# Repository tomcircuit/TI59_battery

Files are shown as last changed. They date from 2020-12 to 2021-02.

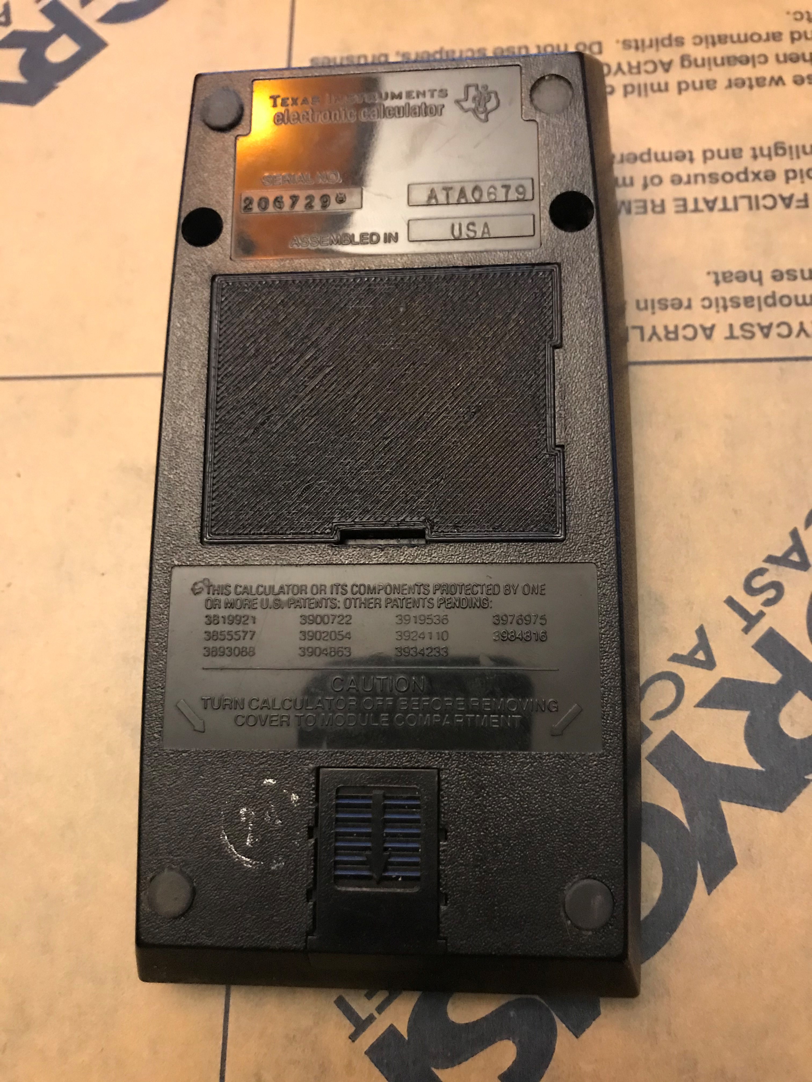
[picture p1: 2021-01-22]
media/TI-59_rear_view_installed.jpg

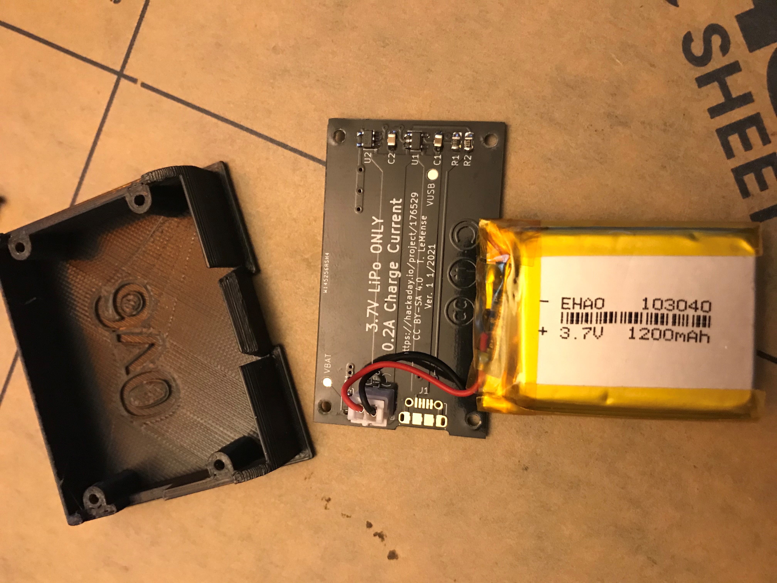
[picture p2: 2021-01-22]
media/TI-59_pack_disassembled.jpg

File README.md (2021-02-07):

 # TI59_battery - LiPo Battery for TI-58/59 Calculators
 
This is my attempt at a LiPo-based battery pack for Texas Instruments Calculators that use the BP01 battery pack,  specifically the TI-58, TI-58C, and TI-59. The original NiCd packs are all dead by now, and rebuilding them is difficult, mostly because it requires cutting apart and then carefully re-assembling the plastic battery retention frame. I thought it would be fun to design a 3D printed housing and re-use the circuitry from my rechargeable HP LiPo battery pack. 

> LiPo chemistry has very specific care-and-feeding when it comes to recharging, **the original charger and charging circuitry will not suffice.**  For this reason, I include a USB receptacle, which allows for charging when removed from the calculator.

The basic idea is to use a gold-flashed (ENIG) PCB as the contact substrate, and mount the LiPo, USB micro B receptacle, and charging circuitry on the opposite side. A **charging LED** is placed on the same side as the contact pads, but in areas where there will be no mechanical interference. A 3D printed plastic holder ties it all together, and mates with the TI calculator case. 
 
## The Housing
I  have several original TI BP01 battery packs, so I was able to carefully measure them and create a 3D model using OpenSCAD. This is essentially a 3D solid 'programming language' which (for me) is much easier to work with than an interactive 3D CAD program. It took several iterations to arrive at a working holder design that would 3D print (FDM) reliably. Note that the holder is best printed "flat side down", but that this orientation is **not ideal** for the retention tab; it wants to break along the FDM layers. I have had good luck with PLA+ material, and even better results with PTEG. 

## The PCB 
The PCB holds the USB micro B connector, the charging circuitry, the protection circuitry, a connector for the LiPo battery, and most importantly the pads that mate with the contacts in the calculator.  The overall size of the PCB is 53mm x 28mm. The material is 1.6mm thick FR4. So that the contact pads do not  tarnish over time, I chose a gold-flash treatment (ENIG). 

The schematic and PCB were designed using KiCAD.

## The LiPo Battery
I wanted a 1S (3.7V) LiPo battery in the neighborhood of 1200mAhr that would fit within the confines of the original pack envelope. This led me to a size "103040" LiPo battery. 

## Putting It All Together
Pretty self-explanatory. I used 0805 size components to allow for easy hand-soldering. Note that D1 (LED) and Z1 (Zener) are both polarized, so pay attention to that. Soldering the USB connector requires a fine-tip iron and some patience, or a hot-air solder station. I use the latter with very good results. 

Connect the battery to the PCB, double-checking that the polarity of the LiPo is matching the **+** and **-** marks on the PCB. Place the battery into the holder in between the two pairs of screw bosses, and then press the PCB into place above it. Four #2 self-tapping stainless steel screws secure the PCB into the 3D printed holder.

## Charge It
Connect a micro-B cable to the board and charge the LiPo battery. The LED will stay lit during the charging process, and extinguish when it is completed. The charge current is about 220mA (0.2C for a 1200mAhr battery). You can adjust R1 to change the current (decrease R1 will increase charging current) if you need to. It took about three hours to charge my battery.

## Use It!
Install the pack into the calculator. Be very careful with the delicate latch retention tab when inserting and removing the holder, because it is fragile and prone to breakage. If it does break, you can usually re-attach the tab with Krazy Glue. Enjoy using your vintage TI programmable calculator!

>February 7. 2021
>Tom LeMense
> Written with [StackEdit](https://stackedit.io/). #

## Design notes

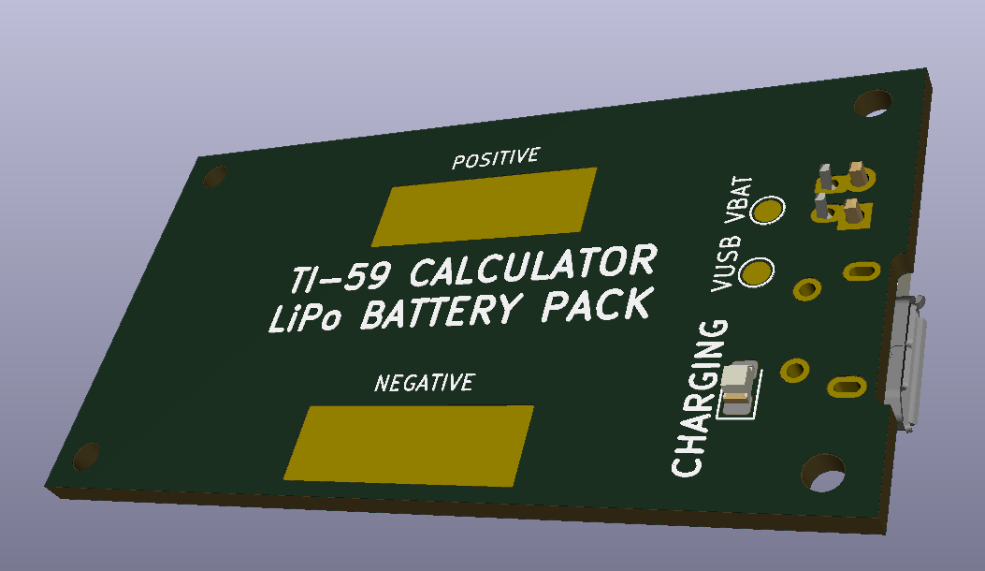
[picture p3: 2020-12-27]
media/initial_pcb_render.PNG

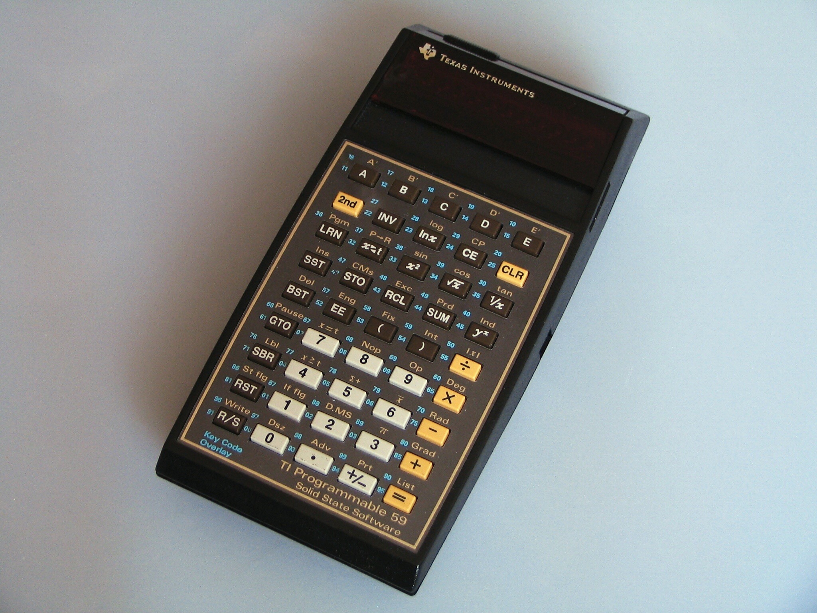
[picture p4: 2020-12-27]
media/TI-59_Half-side_view.jpg

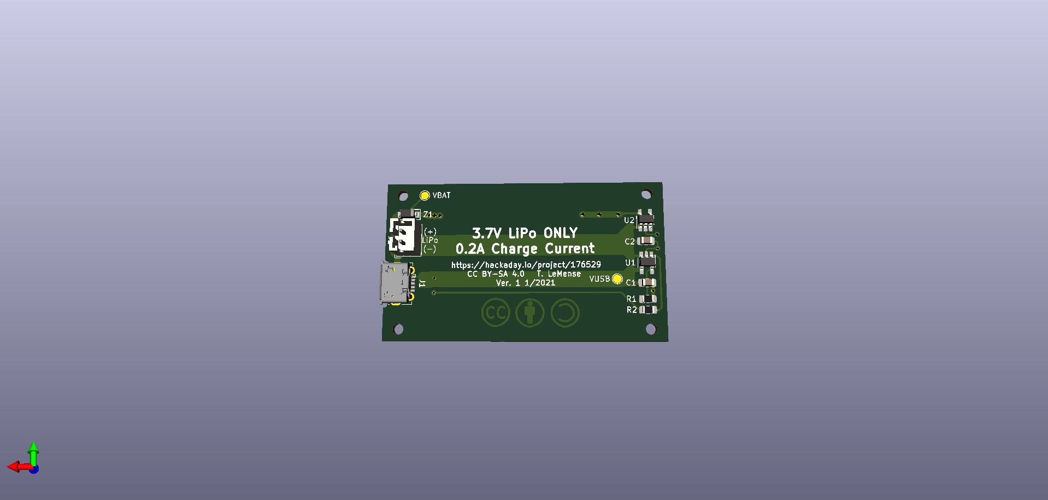
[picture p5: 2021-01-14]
media/routed_pcb_render_bottom.png

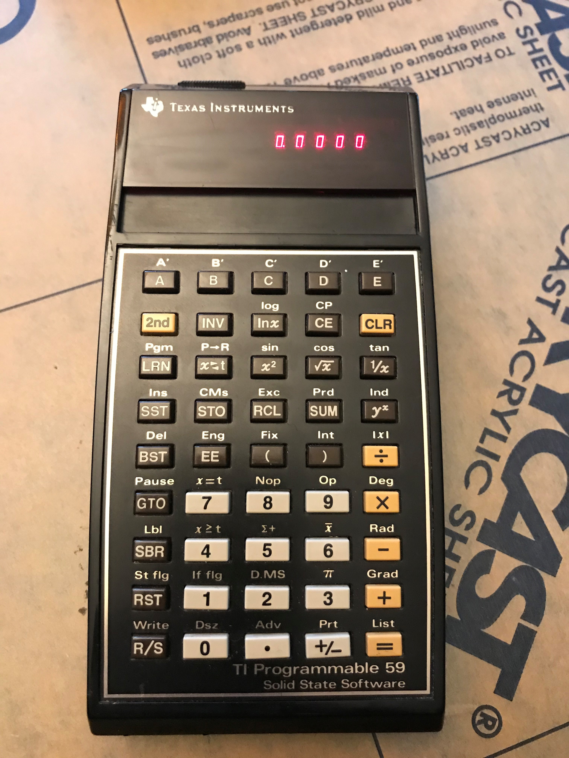
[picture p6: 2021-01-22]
media/TI-59_running.jpg

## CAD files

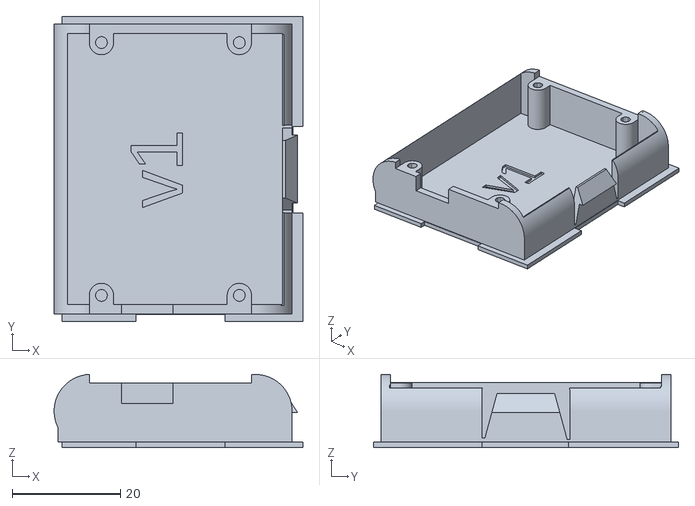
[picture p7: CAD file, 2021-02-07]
mechanical/TI-59_LiPo_holder_1v0.stl
46.0 x 56.4 x 13.5

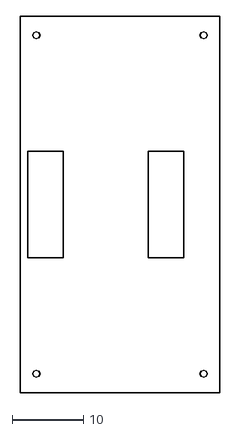
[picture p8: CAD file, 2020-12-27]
mechanical/TI-59_LiPo_holder_cut4_.dxf
28.0 x 53.0

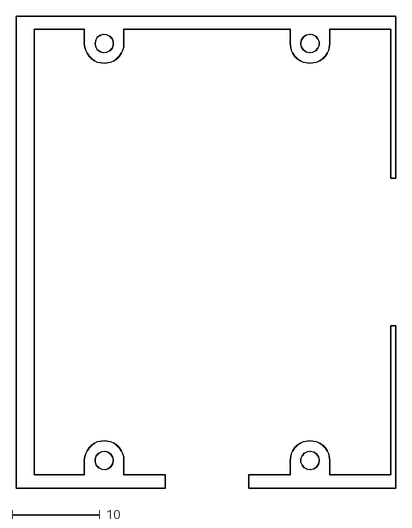
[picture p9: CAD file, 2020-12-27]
mechanical/TI-59_LiPo_holder_cut3_.dxf
43.4 x 53.9

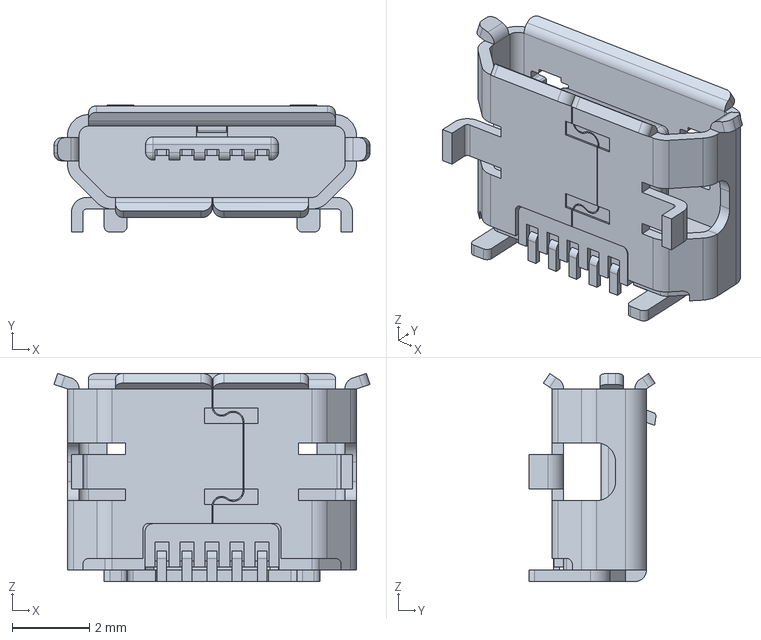
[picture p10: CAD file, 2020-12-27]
electrical/105017-0001_stp/1050170001.stp
8.20 x 3.30 x 5.40 mm

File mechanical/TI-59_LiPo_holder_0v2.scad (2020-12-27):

/*
  TI-58/59 Battery Lid
  This is intended to hold a PCB and a LiPo battery,
  and charge from USB. 

  Dimensions more or less 'cribbed' from a BP-1 and an
  existing STL model that I imported into FreeCAD to measure.

  Version 1.1
  T. LeMense
  December 21, 2020
*/


$fa = 1;
$fs = 0.4;

// baseplate (first surface)
base_t = 1.0;
base_w = 44.85;
base_l = 56.4;
ledge_t = 1.25;
ledge_t1 = 0.75;
ledge_t2 = 1.85;

// PCB information
pcb_t = 1.6;
pcb_w = 28;
pcb_l = 53;
pcb_z = 13.5-pcb_t;
pcb_x = 6.5;

// USB connector cutout
// MOLEX 1050170001
usb_t = 3.75;
usb_w = 9.5;

// "superstructure"
super_w = base_w - ledge_t2 + ledge_t1;
super_l = base_l - 2*ledge_t;
super_h = 5.7;  // the "straight rise" from baseplate
super_z = base_t;  // the "altitude" at which everything starts
super_wall_t = 1.5;
super_floor_t = 0.5;
round_rad = (pcb_z+pcb_t+super_z)/2;

// latch 'tab' is extruded 2D
latch_tab_t = super_wall_t + 0.75;
latch_tab_h = 2.8;
latch_tab_t2 = 0.25;
latch_tab_w = 16.9;
latch_tab_z = 4.95;

p0 = [0, 0];
p1 = [0, latch_tab_h];
p2 = [latch_tab_t2,latch_tab_h];
p3 = [latch_tab_t,0];
tab_points = [p0, p1, p2, p3];
    
// hinge cutouts is extruded 2D
latch_tab_w2 = 12.0;
latch_tab_h2 = super_h+latch_tab_h;

p4 = [0, 0];
p5 = [0, latch_tab_h2];
p6 = [(latch_tab_w - latch_tab_w2)/2,latch_tab_h2];
p7 = [latch_tab_t2,0];
cutout_points = [p4, p5, p6, p7];

echo("inside cavity width is", super_w-2*super_wall_t);
echo("inside cavity length is", super_l-2*super_wall_t);
echo("PCB dimensions are ",pcb_w," x ",pcb_l);

module RoundedBoss(side,height,hole_dia){
    difference() {
        union() {
        cube([side,side/2,height]);
        translate([side/2,side/2,0])
        cylinder(r=side/2,h=height);
        }
        
        translate([side/2,side/2,height/3])
        cylinder(r=hole_dia/2,h=height/1.5);
    }
}

function RoundedBossHoleCenter(side,height,hole_dia) = [side/2,side/2,0];
   

/* 
  Define some "cuts" to export as DXF, to help
  guide the PCB size (cut 1) and PCB hole placement
  (cut 2).

  uncomment the projection.. and the desired translate line
*/

//projection(cut = true) 
//translate([0,0,-base_t/2])   //cut1
//translate([0,0,-pcb_z])   //cut2
//translate([0,0,-10.5])  //cut3
//translate([0,0,-20]) //cut4

union(){
difference() {
    union() {
        
// additive items        
        
    // the baseplate
    cube(size=[base_w, base_l, base_t]);
        
    // the superstructure inner volume
    translate([-0.75, 1.25, super_z])
    cube([super_w, super_l,super_h]); 

    // the locking tab
    translate([-ledge_t1-super_wall_t+super_w,ledge_t+(super_l/2)+(latch_tab_w/2),latch_tab_z+super_z]) 
    rotate([90,0,0]) 
    linear_extrude(height=latch_tab_w) polygon(tab_points);
        
    // the rounded rear wall
    translate([-ledge_t1+5.5,ledge_t,round_rad]) 
    rotate([-90,0,0]) 
    cylinder(r=round_rad,h=super_l);
        
    // the two rounded walls on either side of latch
    translate([-ledge_t1+super_w-round_rad,ledge_t,round_rad]) 
    rotate([-90,0,0]) 
    cylinder(r=round_rad,h=super_l/2-latch_tab_w/2);

    translate([-0.75+super_w-round_rad,base_l-ledge_t,round_rad]) 
    rotate([90,0,0]) 
    cylinder(r=round_rad,h=super_l/2-latch_tab_w/2);
        
    // complete the side walls
    translate ([(5-0.75),ledge_t,super_z])
    cube([super_w-12,super_wall_t,2*round_rad-super_z]);        

    translate ([(5-0.75),base_l-ledge_t-super_wall_t,super_z])
    cube([super_w-12,super_wall_t,2*round_rad-super_z]);
    }
    
// subtractive items            
    
    // remove the locking tab release slot
    translate([base_w - 1.85,1.25+(super_l/2)-(latch_tab_w*0.9/2),-0.25]) 
    cube([2,latch_tab_w*0.9,2]);
    
    // remove the polarizing baseplate notch
    translate([13.8,-1.25,-0.5]) cube([16.4,2.5,2]);
        
    // remove the two hinge cutouts
    translate([-1-super_wall_t+super_w,1.25+(super_l/2)-(latch_tab_w/2)-0.1,super_z])
    rotate([90,0,90])
    linear_extrude(height=2*super_wall_t)
    polygon(cutout_points);
    
    translate([-1+super_wall_t+super_w,1.25+(super_l/2)+(latch_tab_w/2)+0.1,super_z])
    rotate([90,0,-90]) 
    linear_extrude(height=2*super_wall_t) 
    polygon(cutout_points);

    // flatten the rounded wall edges
    translate([-2, 1.25+super_wall_t, super_z+11.5])
    cube([5,super_l-2*super_wall_t,5]);
    translate([base_w-4, 1.25+super_wall_t, super_z+10])
    cube([5,super_l-2*super_wall_t,5]);

    // remove cutout for PCB
    translate([pcb_x,0,super_z+pcb_z])
    cube([pcb_w, pcb_l+4, pcb_t+1]);
    
    // remove cutout for USB micro B
    translate([pcb_x+6,0,super_z+pcb_z-usb_t])
    cube([usb_w,5,5]);

    // remove the superstructure insides
    translate([-0.75+super_wall_t, 1.25+super_wall_t, super_z+super_floor_t])
    cube([super_w-2*super_wall_t, super_l-2*super_wall_t, 20]); 
 
}


// mounting screw bosses
boss_l = 4.5;
boss_dia = 2.1;
boss_inset = (boss_l - boss_dia)/4;

translate([pcb_x,ledge_t+super_wall_t-boss_inset,super_z])
RoundedBoss(boss_l,pcb_z,boss_dia);  // for #2 screw
h1 = [pcb_x+boss_l/2,ledge_t+super_wall_t-boss_inset+boss_l/2,0];

translate([pcb_x+pcb_w-boss_l,ledge_t+super_wall_t-boss_inset,super_z])
RoundedBoss(boss_l,pcb_z,boss_dia);  // for #2 screw
h2 = [pcb_x+pcb_w-boss_l/2,ledge_t+super_wall_t-boss_inset+boss_l/2,0];

translate([pcb_x+boss_l,base_l-ledge_t-super_wall_t+boss_inset,super_z])
rotate([0,0,180])
RoundedBoss(boss_l,pcb_z,boss_dia);  // for #2 screw
h3 = [pcb_x+boss_l/2,base_l-ledge_t-super_wall_t+boss_inset-boss_l/2,0];

translate([pcb_x+pcb_w,base_l-ledge_t-super_wall_t+boss_inset,super_z])
rotate([0,0,180])
RoundedBoss(boss_l,pcb_z,boss_dia);  // for #2 screw
h4 = [pcb_x+pcb_w-boss_l/2,base_l-ledge_t-super_wall_t+boss_inset-boss_l/2,0];


// uncomment this block if a pcb "model" is desired
pcb_model_z = 20;
pcb_model_z = pcb_z+pcb_t/2;
//hole_dia = 0.086 * 25.4;
pad_width = 5;
pad_length = 15;
hole_dia = 1;
pad1_x = 10;
pad2_x = 27;
echo ("pad1 center ",[pad1_x,base_l/2]);
echo ("pad2 center ",[pad2_x,base_l/2]);

translate([0,0,pcb_model_z]) 
    color("green") 
    linear_extrude(height=pcb_t) 
    difference(){
       translate ([pcb_x,(base_l-pcb_l)/2,0]) square ([pcb_w,pcb_l],false); 
       translate([pad1_x,base_l/2,pcb_model_z])        square([pad_width,pad_length],true);
       translate([pad2_x,base_l/2,pcb_model_z])        square([pad_width,pad_length],true);
       translate(h1) circle(d = hole_dia);
       translate(h2) circle(d = hole_dia);
       translate(h3) circle(d = hole_dia);
       translate(h4) circle(d = hole_dia);
    }
//*/
}

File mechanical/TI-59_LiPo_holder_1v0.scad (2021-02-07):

/*
  TI-58/59 Battery Lid for LiPo Pack V1
  This is intended to hold a PCB and a LiPo battery,
  and charge from USB. 

  Dimensions measured from several TI-58 and TI-59 calculators and two BP-1A packs.
  
  0.4 and earlier - very rough 
  
  0.5 - extended tab overhang to increase engagement with calculator latch
  
  0.6 - reduced contact_zabs to 13.5 to prevent PCB screws and LED from interfering with inside of TI-59
  
  0.7 - rounded cutout on inside of tab hinge to help de-stress and prevent breakage. Increased slope of latch tab to make insertion into calculator easier
  
  0.8 - removed cutout (made tab worse). This becomes V1

  T. LeMense
  February 7, 2021
*/


$fa = 1;
$fs = 0.4;

// L is length, and is along Y AXIS
// W is width, and is along X AXIS
// H is height, and is along Z AXIS

// baseplate (first surface)
base_t = 1.0;  // base thickness (measured)
base_w = 44.5;  // width (measured)
base_w3 = 14.4;  // ledge width from pol slot to latch end (measured)
base_w1 = 13.6;  // ledge w from round end to pol slot (measured)
base_w2 = base_w-base_w1-base_w3;  // calculate pol slot w (measured 16.4mm)
base_l = 56.4;   // length (measured)
ledge_t = 1.4;  // ledge along short sides (improved)
ledge_t1 = 0.75; // ledge step-back along curved long side
ledge_t2 = 2.0;  // ledge along latch side (measured)

//contact Z offset (absolute to bottom of base)
//keep below 15 to avoid interference with innards of TI59!
contact_zabs = 13.5; 

// PCB information
pcb_t = 1.6;
pcb_w = 30;
pcb_l = 53;
pcb_z = contact_zabs-pcb_t-base_t;
pcb_x = 5;

// USB connector cutout
// MOLEX 1050170001
usb_h = 3.75;
usb_w = 9.5;

// "superstructure"
super_w = base_w - ledge_t2 + ledge_t1; // width (short edge)
super_l = base_l - 2*ledge_t;  // length (long edge)
super_h = 5.7;  // the "straight rise" from baseplate
super_wall_t = 1.75;
super_floor_t = 0.5; // additional floor thickness
round_rad = (pcb_z+pcb_t+base_t)/2;

// latch 'tab' is an extruded polygon
latch_tab_w = super_wall_t + 1.0; // extent of tab past wall
latch_tab_h = 3.5;
latch_tab_w2 = 0.5;
latch_tab_l = 16.0;
latch_tab_z = 5.5;   // relative to base_t

p0 = [0, 0];
p1 = [0, latch_tab_h];
p2 = [latch_tab_w2,latch_tab_h];
p3 = [latch_tab_w,0];
tab_points = [p0, p1, p2, p3];
    
// hinge cutout is extruded 2D
latch_tab_l2 = 10.0;
latch_tab_h2 = super_h+latch_tab_h;

p4 = [0, 0];
p5 = [0, latch_tab_h2];
p6 = [(latch_tab_l - latch_tab_l2)/2,latch_tab_h2];
p7 = [latch_tab_w2,0];
cutout_points = [p4, p5, p6, p7];

echo("inside cavity width is", super_w-2*super_wall_t);
echo("inside cavity length is", super_l-2*super_wall_t);
echo("PCB dimensions are ",pcb_w," x ",pcb_l);

module RoundedBoss(side,height,hole_dia){
    difference() {
        union() {
        cube([side,side/2,height]);
        translate([side/2,side/2,0])
        cylinder(d=side,h=height);
        }
        
        translate([side/2,side/2,height/3])
        cylinder(d=hole_dia,h=height/1.5);
    }
}

function RoundedBossHoleCenter(side,height,hole_dia) = [side/2,side/2,0];
   

/* 
  Define some "cuts" to export as DXF, to help
  guide the PCB size (cut 1) and PCB hole placement
  (cut 2). These are translated to place PCB corner at 
  origin.  Note that the PCB model must be enabled, and
  the PCB Z at 20, in order to make cut4 useful.

  uncomment the projection.. and the desired translate line. Render. Export as DXF
*/

//projection(cut = true) 
//translate([-pcb_x,-(base_l-pcb_l)/2,-base_t/2])   //cut1 = base extent
//translate([-pcb_x,-(base_l-pcb_l)/2,-10.5])  //cut3 = cavity inside w.r.t PCB
//translate([-pcb_x,-(base_l-pcb_l)/2,-20]) //cut4 = PCB cuts + contacts + holes

union(){
difference() {
    union() {
        
// additive items        
        
    // the baseplate
    cube(size=[base_w, base_l, base_t]);
        
    // the superstructure inner volume
    translate([-ledge_t1, ledge_t, base_t])
    cube([super_w, super_l,super_h]); 

    // the locking tab
    translate([-ledge_t1-super_wall_t+super_w,ledge_t+(super_l/2)+(latch_tab_l/2),latch_tab_z+base_t]) 
    rotate([90,0,0]) 
    linear_extrude(height=latch_tab_l) polygon(tab_points);
        
    // the rounded rear wall
    translate([-ledge_t1+6,ledge_t,round_rad]) 
    rotate([-90,0,0]) 
    cylinder(r=round_rad,h=super_l);
        
    // the two walls to either side of latch
    translate([-ledge_t1+super_w-round_rad,ledge_t,round_rad]) 
    rotate([-90,0,0]) 
    cylinder(r=round_rad,h=super_l/2-latch_tab_l/2);

    translate([-ledge_t1+super_w-round_rad,base_l-ledge_t,round_rad]) 
    rotate([90,0,0]) 
    cylinder(r=round_rad,h=super_l/2-latch_tab_l/2);
        
    // complete the side walls
    translate ([(5-0.75),ledge_t,base_t])
    cube([super_w-12,super_l,2*round_rad-base_t]); 
    
    }
    
// subtractive items            
    
    // remove tab release slot from base
    translate([base_w - 1.85,1.25+(super_l/2)-(latch_tab_l/2),-0.25]) 
    cube([2,latch_tab_l,2]);
    
    // remove polarizing notch from base
    translate([base_w1,-1.25,-0.5]) cube([base_w2,2.50,2]);
        
    // remove the two hinge cutouts
    translate([super_w-super_wall_t-1,ledge_t+(super_l/2)-(latch_tab_l/2)-0.1,base_t+0.75])
    rotate([90,0,90])
    linear_extrude(height=2*super_wall_t)
    polygon(cutout_points);
    
    translate([-1+super_wall_t+super_w,ledge_t+(super_l/2)+(latch_tab_l/2)+0.1,base_t+0.5])
    rotate([90,0,-90]) 
    linear_extrude(height=2*super_wall_t) 
    polygon(cutout_points);
    
    // de-stress the tab hinge
//translate([-ledge_t1+super_w-2.5,ledge_t+(super_l/2)-(latch_tab_l/2)-0.1,base_t+2.25])
//rotate([-90,0,0])
//cylinder(r=1.75,h=latch_tab_l);

    // flatten the rounded wall edges
    translate([-2, 1.25+super_wall_t, base_t+12.5])
    cube([5,super_l-2*super_wall_t,5]);
    translate([base_w-4, 1.25+super_wall_t, base_t+10])
    cube([5,super_l-2*super_wall_t,5]);

    // remove cutout for PCB
    translate([pcb_x,0,base_t+pcb_z])
    cube([pcb_w, pcb_l+4, pcb_t+1]);
    
    // remove cutout for USB micro B
    translate([pcb_x+6,0,base_t+pcb_z-usb_h])
    cube([usb_w,4*super_wall_t,2*usb_h]);

    // remove the superstructure insides
    translate([super_wall_t-ledge_t1, ledge_t+super_wall_t, base_t+super_floor_t])
    cube([super_w-2*super_wall_t, super_l-2*super_wall_t, 20]); 
    
    // etch some text into the floor
    translate([base_w/2,base_l/2,base_t])
    rotate([0,0,90])
    linear_extrude(3)
    text( "v1", size= 10, ,halign = "center", valign = "bottom" );
}

// mounting screw bosses
boss_l = 4.5;
boss_h_dia = 2.2;
boss_inset = (boss_l - boss_h_dia)/4;

translate([pcb_x,ledge_t+super_wall_t-boss_inset,base_t])
RoundedBoss(boss_l,pcb_z,boss_h_dia);  // for #2 screw
h1 = [pcb_x+boss_l/2,ledge_t+super_wall_t-boss_inset+boss_l/2,0];

translate([pcb_x+pcb_w-boss_l,ledge_t+super_wall_t-boss_inset,base_t])
RoundedBoss(boss_l,pcb_z,boss_h_dia);  // for #2 screw
h2 = [pcb_x+pcb_w-boss_l/2,ledge_t+super_wall_t-boss_inset+boss_l/2,0];

translate([pcb_x+boss_l,base_l-ledge_t-super_wall_t+boss_inset,base_t])
rotate([0,0,180])
RoundedBoss(boss_l,pcb_z,boss_h_dia);  // for #2 screw
h3 = [pcb_x+boss_l/2,base_l-ledge_t-super_wall_t+boss_inset-boss_l/2,0];

translate([pcb_x+pcb_w,base_l-ledge_t-super_wall_t+boss_inset,base_t])
rotate([0,0,180])
RoundedBoss(boss_l,pcb_z,boss_h_dia);  // for #2 screw
h4 = [pcb_x+pcb_w-boss_l/2,base_l-ledge_t-super_wall_t+boss_inset-boss_l/2,0];



/*
// uncomment this block if a pcb "model" is desired
pcb_model_z = 20;
//pcb_model_z = pcb_z+base_t;
//hole_dia = 0.086 * 25.4;
pad_width = 5;
pad_length = 15;
hole_dia = 1;
pad1_x = 10;
pad2_x = 27;
echo ("pad1 center ",[pad1_x,base_l/2]);
echo ("pad2 center ",[pad2_x,base_l/2]);

translate([0,0,pcb_model_z]) 
    color("green") 
    linear_extrude(height=pcb_t) 
    difference(){
       translate ([pcb_x,(base_l-pcb_l)/2,0]) square ([pcb_w,pcb_l],false); 
       translate([pad1_x,base_l/2,pcb_model_z])        square([pad_width,pad_length],true);
       translate([pad2_x,base_l/2,pcb_model_z])        square([pad_width,pad_length],true);
       translate(h1) circle(d = hole_dia);
       translate(h2) circle(d = hole_dia);
       translate(h3) circle(d = hole_dia);
       translate(h4) circle(d = hole_dia);
    }
//*/
}

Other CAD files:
mechanical/TI-59_LiPo_holder_0v5.scad
mechanical/TI-59_LiPo_holder_0v5_latch_test.scad

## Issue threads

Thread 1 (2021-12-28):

Suggestion - simple way to let TI charging circuit power and charge calculator

magore, 2021-12-28:
I love your project. This is just a suggestion and not a bug report.

I have a number of TI-59 calculators and your project got me thinking.
I wondered if there was a way to use the existing TI charging circuit (basically a bridge rectifier feed from an externally AC transformer - that was current limited by design) to both charge and power the calculator when plugged in?

First requirement is filter and stabilize the power from the spring contacts. Let that filtered voltage feed a Lipo charging circuit in the battery pack that provides both load/out and charging on its output. When the charger is plugged in the calculator runs from the charger and the LIPO can also charge if needed. When not plugged in calculator runs only from the LIPO. The bridge rectifier prevents back flow from the charger.

Testing I have tried - I have connected a simple LIPO charging circuit to the spring contacts filtered with just a 1000uF cap. With the calculator OFF the spring contacts measure 4.3V and can fully charge the LIPO. However with the calculator ON the voltage drops to 4.0V. So basically the LIPO will not get a full charge unless the calculator is off.

tomcircuit, 2021-12-31:
Thanks for writing, and I’m glad you found my project interesting! I has some thoughts about trying to do what you propose, but didn’t like the complexity (i.e. I was lazy!)

I seem to recall reading that the TI AC charger current limiting was set so that it would just manage to trickle charge the NiCd cells while the calc was operating. So your measurement of 4V with calc on (and no card reader motor I presume) sounds about right.  I think the most straightforward solution would be to use a boost-type charging circuit, such as used with solar cells. You would also likely need to set the charging current much lower (10’s of mA) to avoid “brownout”. Please keep me posted as to your progress!!

magore, 2022-01-14:
Thanks for the feedback

Closed 2022-01-14.

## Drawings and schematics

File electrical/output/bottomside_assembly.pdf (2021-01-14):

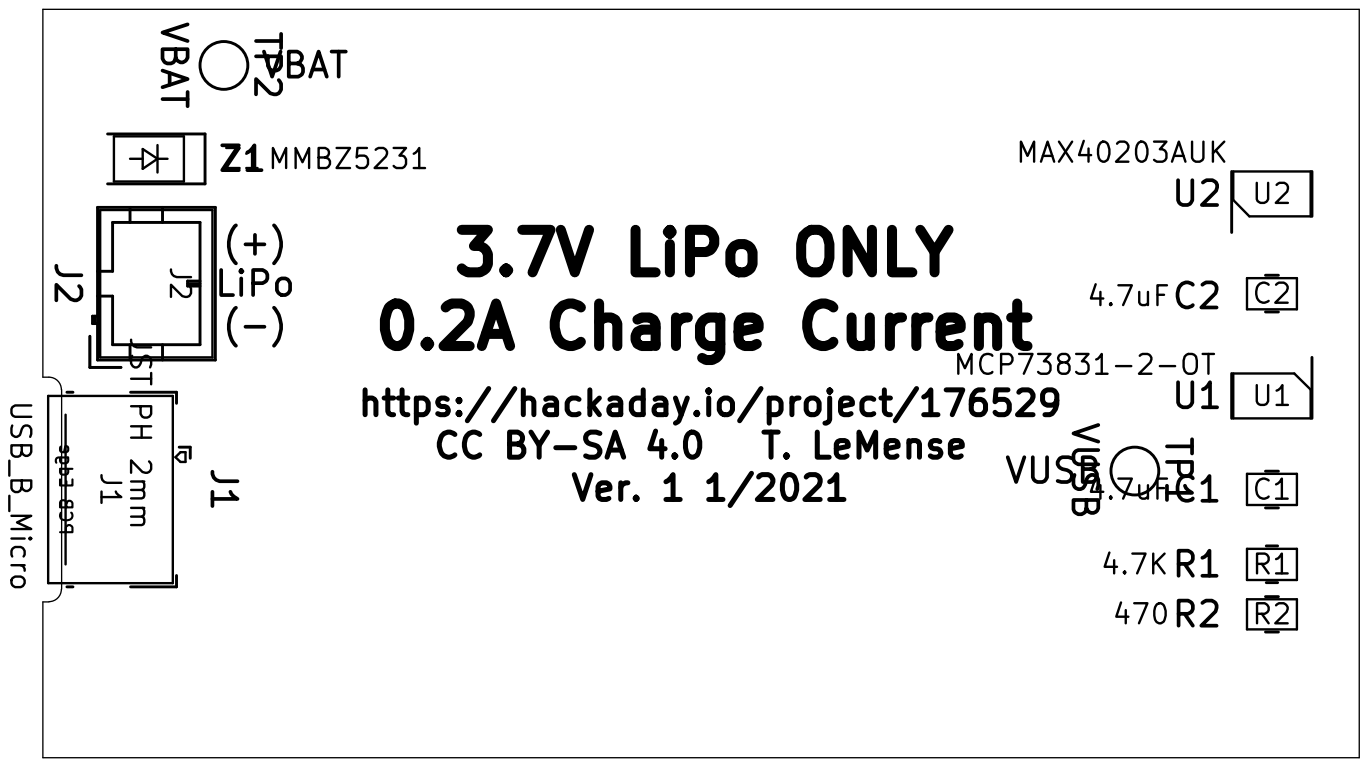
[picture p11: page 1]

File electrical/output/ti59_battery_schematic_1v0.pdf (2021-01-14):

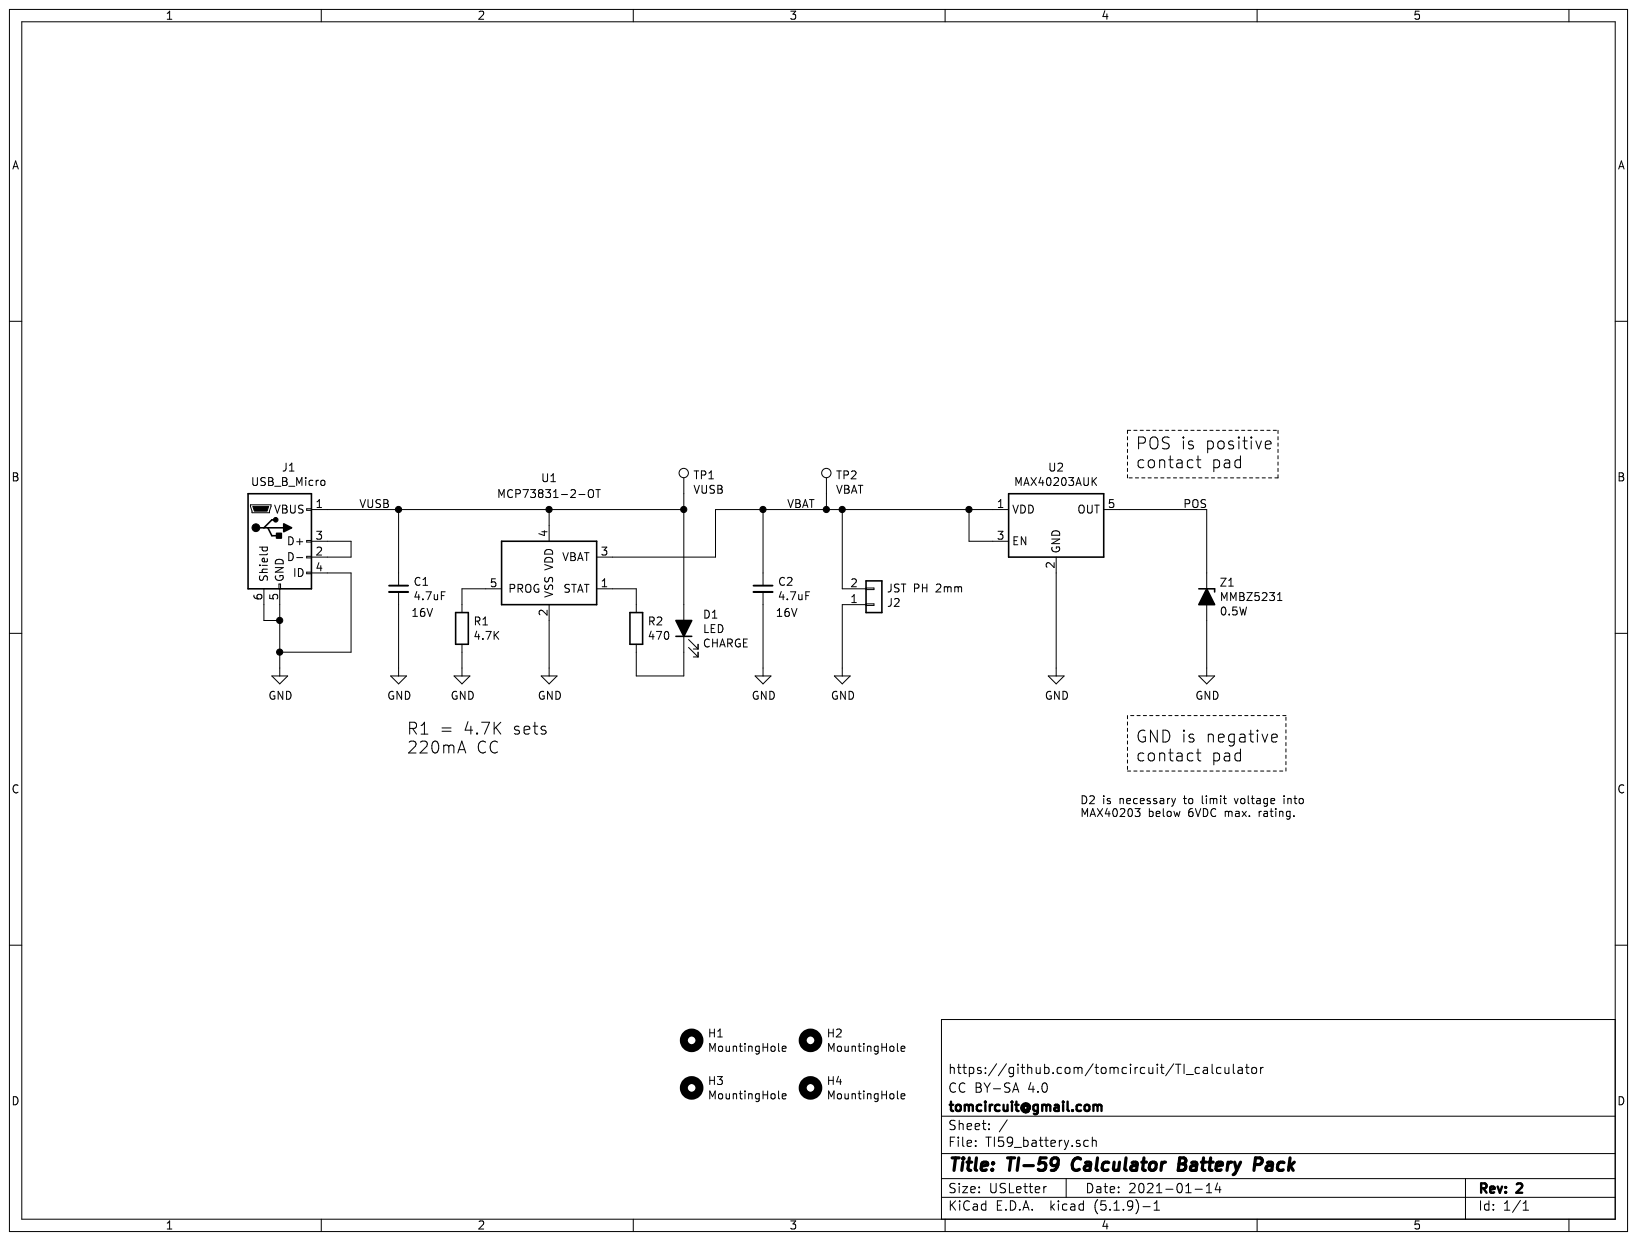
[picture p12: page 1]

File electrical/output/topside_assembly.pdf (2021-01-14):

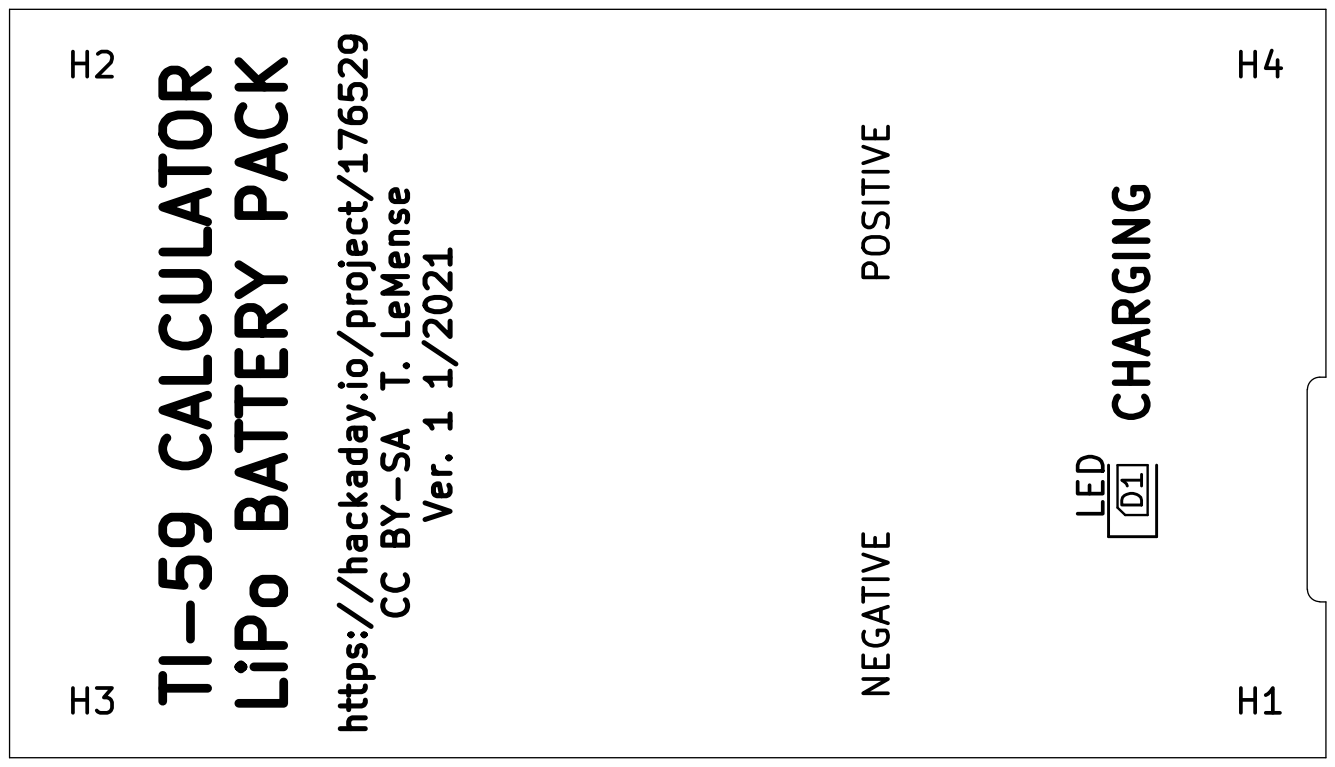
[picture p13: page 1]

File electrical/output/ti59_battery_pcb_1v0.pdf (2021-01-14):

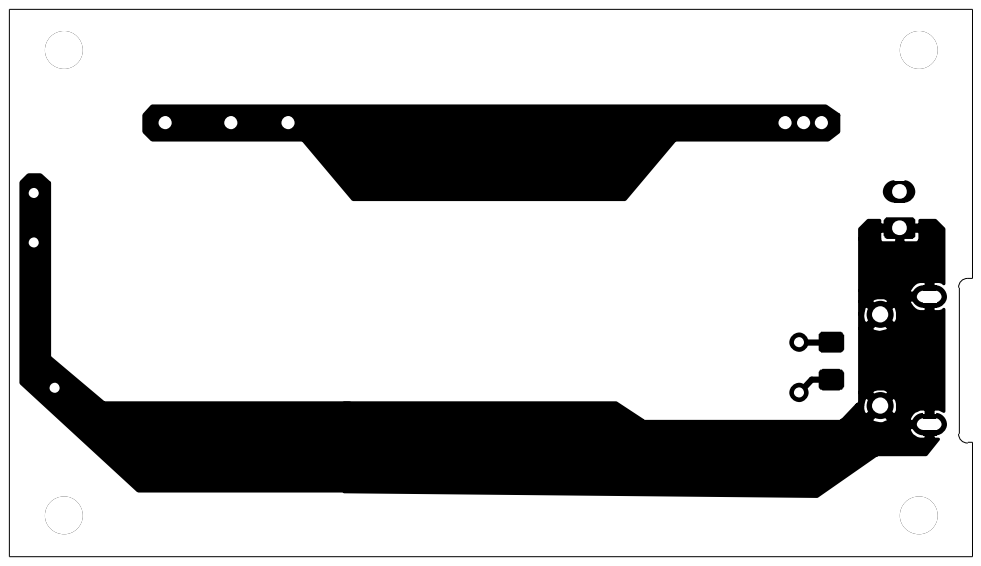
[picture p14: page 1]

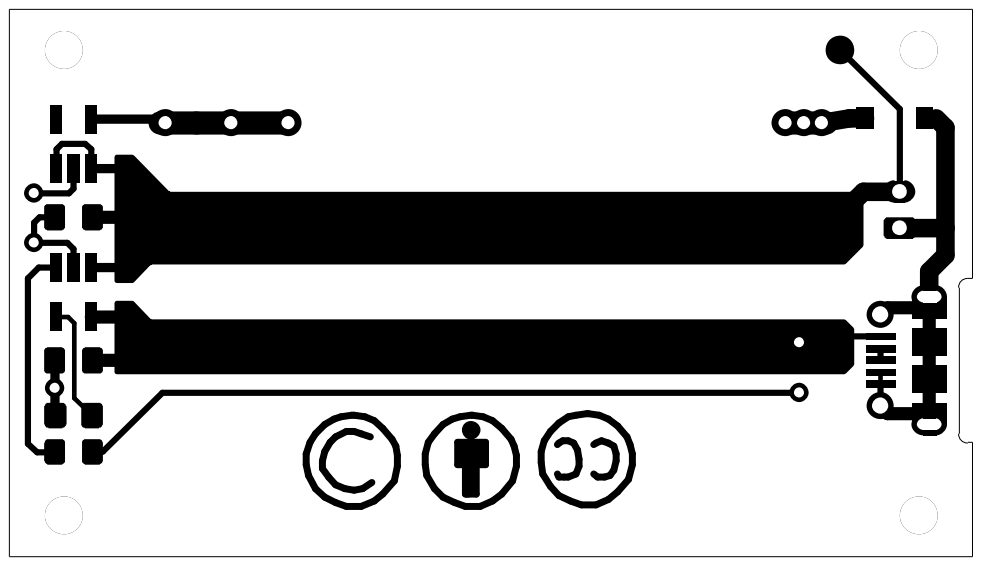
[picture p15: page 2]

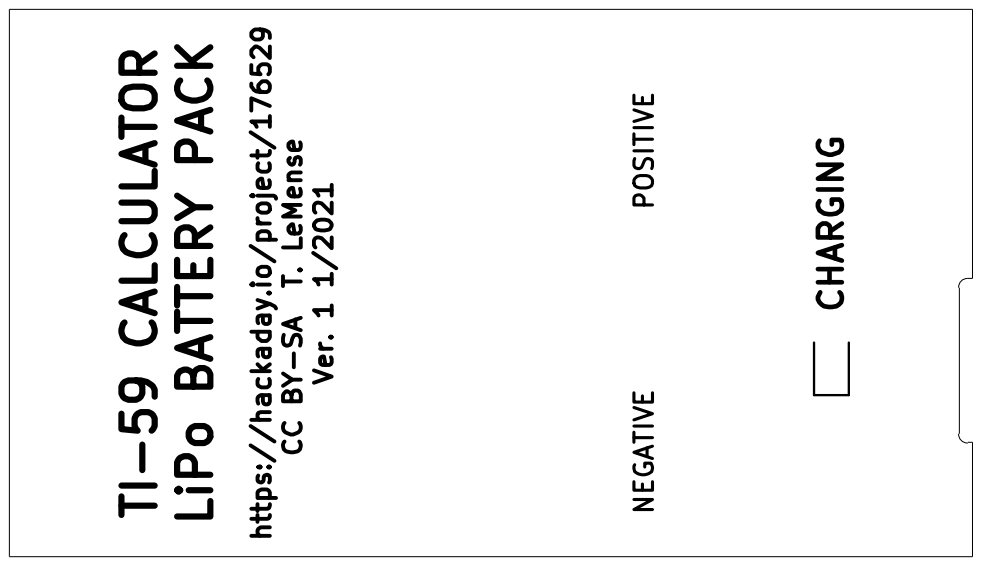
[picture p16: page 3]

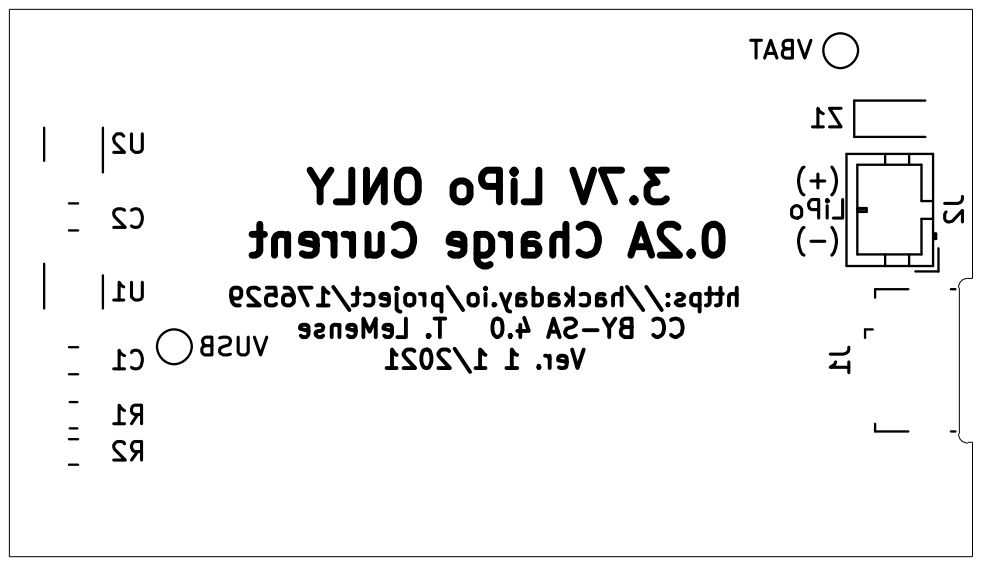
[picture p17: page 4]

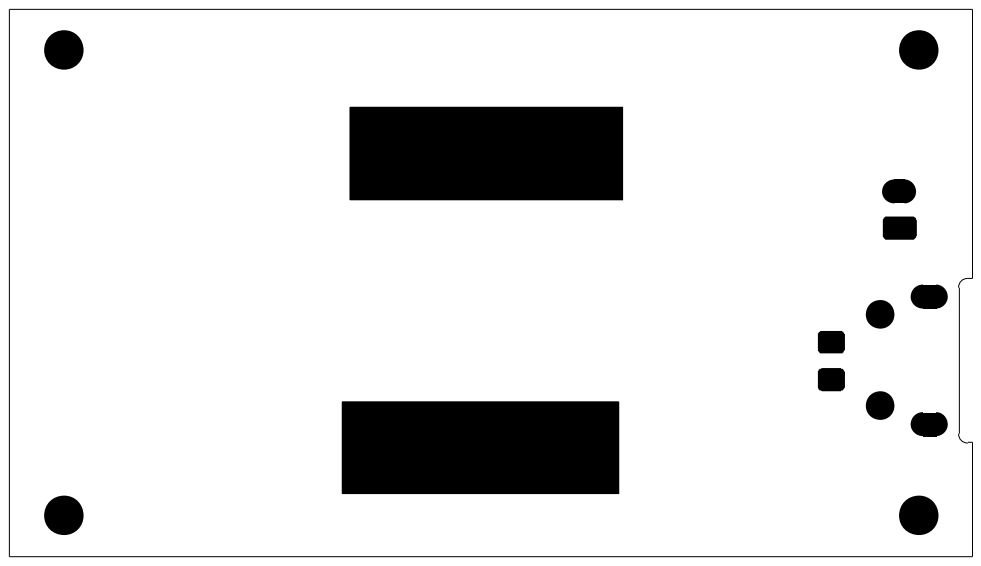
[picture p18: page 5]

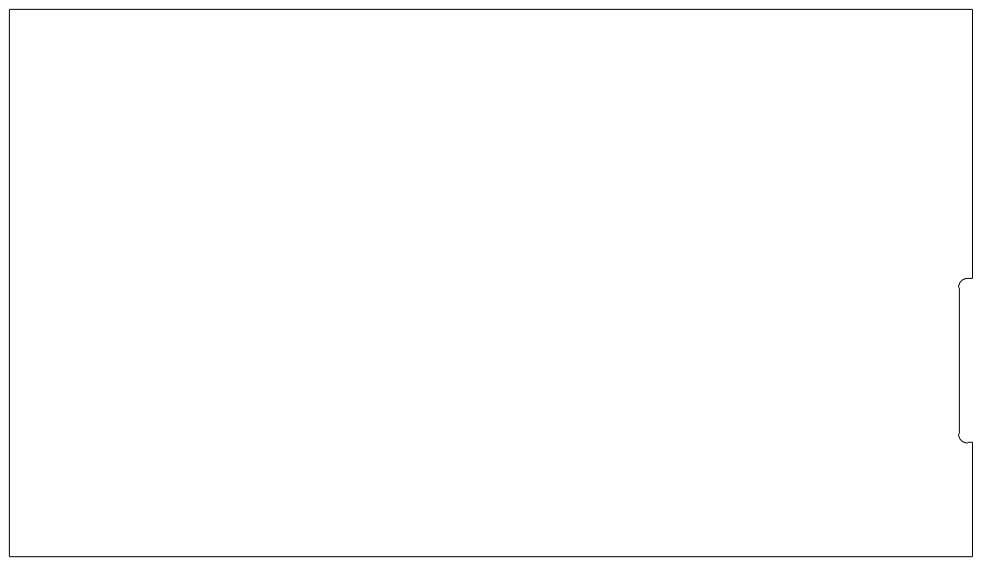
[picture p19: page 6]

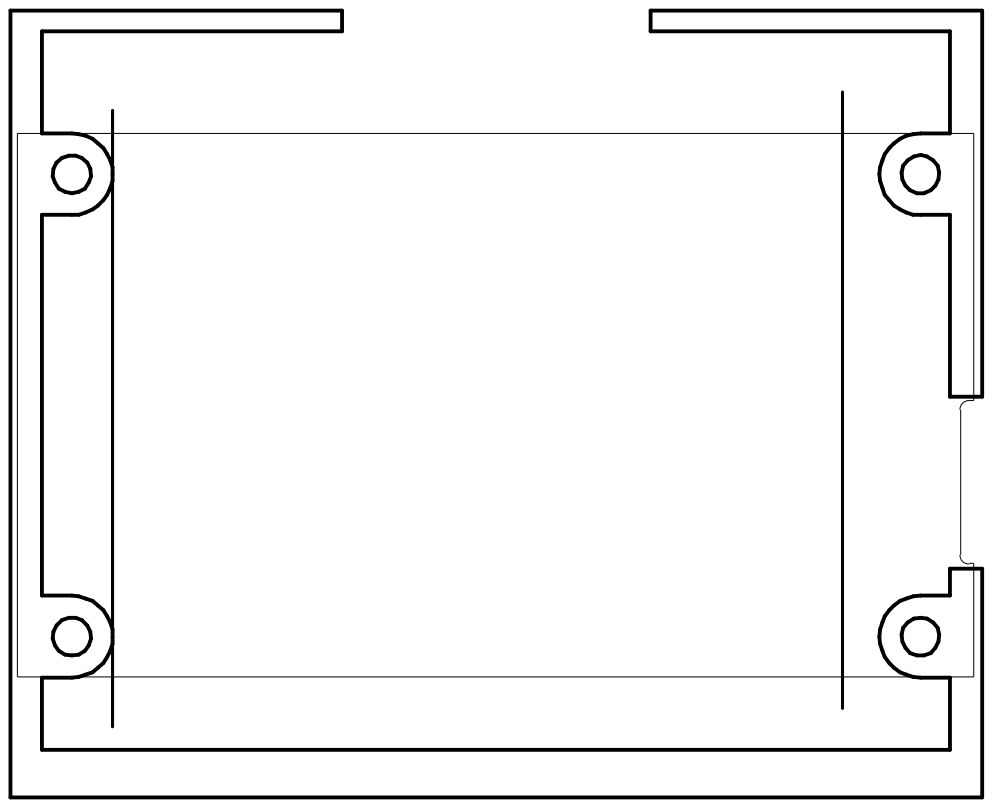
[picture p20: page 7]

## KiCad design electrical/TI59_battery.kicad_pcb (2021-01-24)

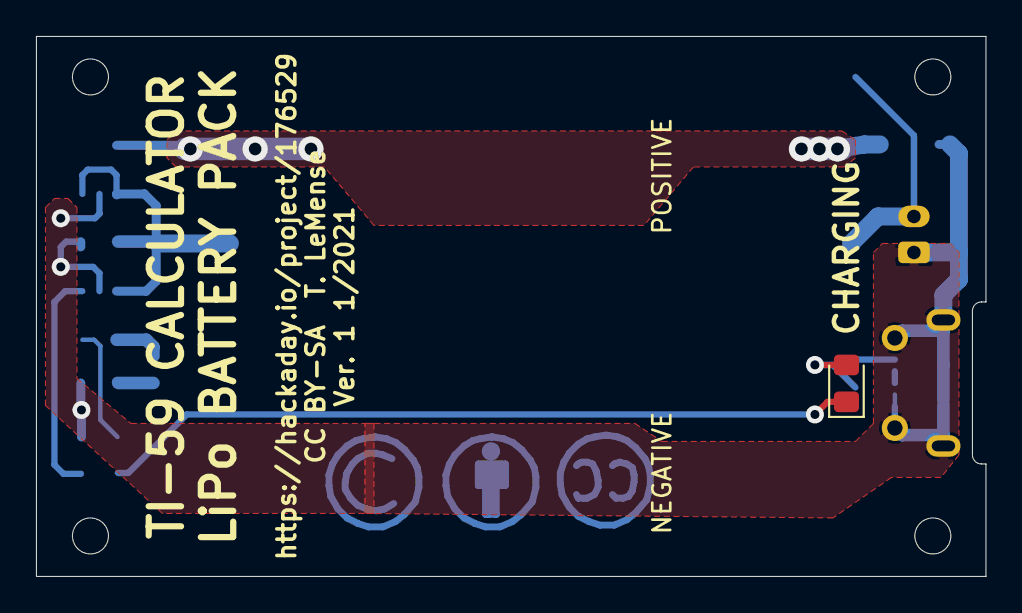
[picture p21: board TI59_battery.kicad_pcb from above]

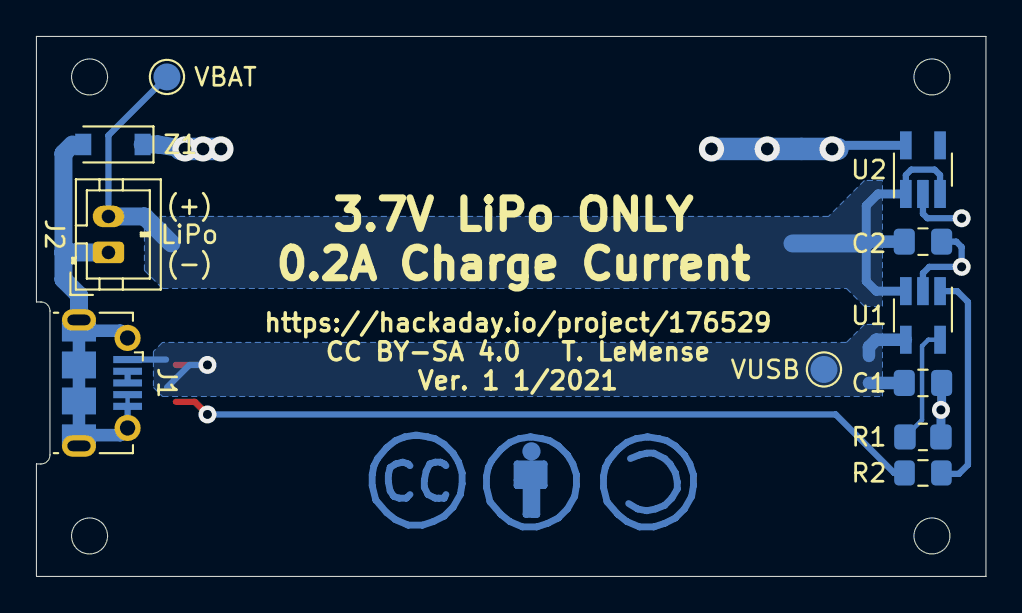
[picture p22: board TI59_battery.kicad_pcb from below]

Board: 2 copper layers, 52.8 x 30.0 mm, 16 parts (11 on the bottom side), 8 nets.

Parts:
C1, C2: 4.7uF; C_0805_2012Metric_Pad1.18x1.45mm_HandSolder
D1: LED; LED_0805_2012Metric_Pad1.15x1.40mm_HandSolder
H1, H2, H3, H4: MountingHole; MountingHole_2mm
J1: USB_B_Micro; USB_Micro-B_Molex-105017-0001
J2: JST PH 2mm; JST_PH_B2B-PH-K_1x02_P2.00mm_Vertical
R1: 4.7K; R_0805_2012Metric_Pad1.20x1.40mm_HandSolder
R2: 470; R_0805_2012Metric_Pad1.15x1.40mm_HandSolder
TP1: VUSB; TestPoint_Pad_D1.5mm
TP2: VBAT; TestPoint_Pad_D1.5mm
U1: MCP73831-2-OT; SOT-23-5_HandSoldering
U2: MAX40203AUK; SOT-23-5_HandSoldering
Z1: MMBZ5231; D_SOD-123

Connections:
/POS: U2.5, Z1.1
/VBAT: C2.1, J2.2, TP2.1, U1.3, U2.1, U2.3
/VUSB: C1.1, D1.2, J1.1, TP1.1, U1.4
GND: C1.2, C2.2, J1.4, J1.5, J1.6, J2.1, R1.2, U1.2, U2.2, Z1.2
unnamed: D1.1, R2.2
unnamed: J1.2, J1.3
unnamed: R1.1, U1.5
unnamed: R2.1, U1.1

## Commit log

2020-12-27 Delete TI59_pcb_outline.dxf
    removed old (and incorrect) PCB outline DXF file from mechnical directory
    [TI59_pcb_outline.dxf]
2020-12-27 work on PCB routing...
    [TI59_battery.kicad_pcb]
2021-01-14 Version 1 Release
    TI59 LiPo Battery Pack V1
    PCB and Schematic are frozen.
    Holder 0v5 is frozen
    Holder to be checked when PCB's are available.
    [0v5_latch_test.stl, TI-59_LiPo_holder_0v2.stl, TI-59_LiPo_holder_0v4.scad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]
2021-01-14 Update README.md
    PCB and holder status
2021-01-22 Additional JPG of LiPo Pack
2021-01-24 holder 0v6 and 0v7 upload
    0v6 fits into TI58 and TI59
    0v7 is an attempt to improve retention latch
    [0v5_latch_test.stl, TI-59_LiPo_holder_0v4.scad, TI-59_LiPo_holder_0v5.stl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]
2021-02-07 removed old v6 and v7 mech files
    [TI-59_LiPo_holder_0v6.scad, TI-59_LiPo_holder_0v7.scad, TI-59_LiPo_holder_0v7.stl]
2021-02-07 updated README
    more info on the holder and final assembly. #2 SS screws indicated. Care with retention tab noted.
2021-02-07 removed 0v5 PCB guide DXF files
    [TI-59_holder_0v5_keepout_cut.dxf, TI-59_holder_0v5_pcb_cut.dxf]
2021-02-07 TI-58/59 Holder v1
    Version 0v8 tested and ready for release, so bumped to v1.
    [TI-59_LiPo_holder_1v0.scad, TI-59_LiPo_holder_1v0.stl]

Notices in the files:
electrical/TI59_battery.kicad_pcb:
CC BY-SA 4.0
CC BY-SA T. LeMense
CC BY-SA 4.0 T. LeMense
